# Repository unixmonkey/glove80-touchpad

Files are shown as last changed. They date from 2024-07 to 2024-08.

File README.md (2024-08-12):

# glove80-touchpad
Touchpad sidecar mod for the Glove80 keyboard using the [ERGO Touchpad](https://ergonomictouchpad.com/ergonomic_touchpad.php) ([Amazon](https://www.amazon.com/gp/product/B087Z7RGGK/)).

glove80-touchpad

## Why

I recently started getting RSI-like pain and went on a deep dive into the word of ergonomic split keyboards, but I knew a large part of my issue was my mouse usage habits, and that moving from the keyboard to the mouse (or trackpad) over and over again certainly wasn't helping.

Unfortunately, there currently are very few commercially available ergonomic keyboards that have built-in pointing devices.
However, the [MoErgo Glove80](https://www.moergo.com/collections/glove80-keyboards) keyboard tries to be highly ergonomic, as well as [customizable](https://www.moergo.com/pages/glove80-ergonomic-keyboard-customization) platform, and even provides built-in anchor points and some basic 3d models that can be used to add your own pointing devices right between the thumb cluster and forefinger areas. I figured this could be how I could possibly _make_ the Glove80 the perfect keyboard for me.

So I bought the Glove80, and a 3d printer, and got to work. This is helping me, and so I hope my efforts can help others.

## What you'll need

1. The [MoErgo Glove80 keyboard](https://www.moergo.com/collections/glove80-keyboards)
2. A 3D printer (or a friend/library/makerspace/business with one)
3. [ERGO Touchpad](https://ergonomictouchpad.com/ergonomic_touchpad.php)
4. 2.5mm screws (for the Glove80 mounting holes). I'm using 8mm deep ones I got in [this kit](https://www.amazon.com/dp/B0BLCFD9HR)
5. These [3d model files](/models/)

Optionally, if you want the USB cable to be detachable:

6. Soldering equipment, and a steady hand ([this is a great kit for cheap](https://www.amazon.com/gp/product/B07Q2B4ZY9/ref=ppx_yo_dt_b_search_asin_title?ie=UTF8&th=1))
8. A USB-C breakout board (I used [this treedix board](https://treedix.com/products/treedix-4pcs-usb-type-c-breakout-board-serial-basic-breakout-female-connector-type-pcb-converter-board) also available on [Amazon here](https://www.amazon.com/dp/B096M2HQLK)

## Test the touchpad

While unlikely, it's entirely possible the touchpad may be DOA (Dead on Arrival), so plug it in to a computer and make sure it works before we start questioning our sanity if it somehow no longer works after soldering.

The ERGO works a little different compared to many touchpads, but I found it very easy to adapt to:
- Tap to left-click
- Tap in the top-right corner to right-click
- Slide your finger along the rightmost edge to scroll
- Double-tap to click and hold (useful for dragging windows/files around) - This one takes a little practice
  
ergo-touchpad

It comes with velcro, so if you have a regular sidecar printed, you can use mostly out-of-the-box like that, but I wanted something a bit cleaner.

## 3d printing

This 3d model works pretty well and looks fairly sharp, in my opinion. It's main features are:

- It is expanded to the edge of the thumb cluster, and flares out to completely support the touchpad
- It is perfectly flush to the Ergo touchpad, when the velcro is removed
- It is angled and tilted just a bit to make it easier to use with your index finger
- It has a hole and platform for a USB-C connector and board (optional)
- It has a bottom plate (also optional)

right-hand-touchpad-model
right-hand-touchpad-back

If you want to use on the left-hand of the Glove80, mirror the model along the flat outer surface.

## Assembly

Carefully peel the velcro off of the back of the Ergo touchpad, making sure to not damage the USB cable that is tucked under it.

peel-velcro

Note: Those two green buttons are right and left click, so you could possibly wire them up to actual buttons if desired. I might try a version with a left-click button to make dragging easier.

Now, you should be able to thread the USB cable through the hole in the model, and optionally secure it with some tape on the underside.

If you don't care about a detachable USB cable, you can stop here, and simply screw the sidecar to your Glove80 and stop here.

## Adding a Detachable USB-C Connector

The model includes a small platform and hole for a Treedix USB-C connector & board. This can be used to make it easy to unplug the whole thing at the box, instead of at the computer.

1. Cut the Ergo Touchpad USB cable about 4-5 inches (100-130mm) from the board
2. Score and peel away an inch (~20mm) or so of the protective jacket to expose the USB wires inside
3. On each individual wire, score and peel back each wire to expose about 2-3mm of copper
4. Melt a very small amount of solder onto the exposed copper to get them nice and ready for soldering
5. Melt a very small amount of solder onto the Treedix connector pads where we will be attaching the wires

This is how it should look all wired up:

touchpad soldering

Here it is in the enclosure, with the USB-C board screwed down (this was a version with a circle for a cutout, which didn't have room for the connector, so I had to cut it some. The updated models account for this):

back-view

Then, tuck the wires inside and screw on the back (if you printed that model), with 2.5mm screws (same as the sidecar mounts). This back model could use wider holes to recess those screws.

back-on

## Final product

This is a video of me using both the Touchpad and Trackpoint sidecars, so you can see how the gestures, & wrist positions, & movements look:

Using the Touchpad & Trackpoint (https://youtu.be/VEFaY-3PMP4)

## TODO

- Experiment with the shape of the outer edge
- Possibly wire up buttons to Kailh switches

## See Also

- My [Glove80 Ergo Trackpoint mod](https://github.com/unixmonkey/glove80-trackpoint)
- My [Glove80 Wireless Trackball mod](https://github.com/unixmonkey/glove80-trackball) (in progress)

I love the freedom from RSI pain this keyboard has saved me from, and I love it even more with these mouse-replacements. My pain has gotten much more managable, and I've enjoyed getting into 3d modeling and printing!

Thank you to the many people who have posted on the [MoErgo Discord Community](https://www.moergo.com/discord) that helped inspire me to make this happen, and are always dropping great tips on how to optimize my computing experience.

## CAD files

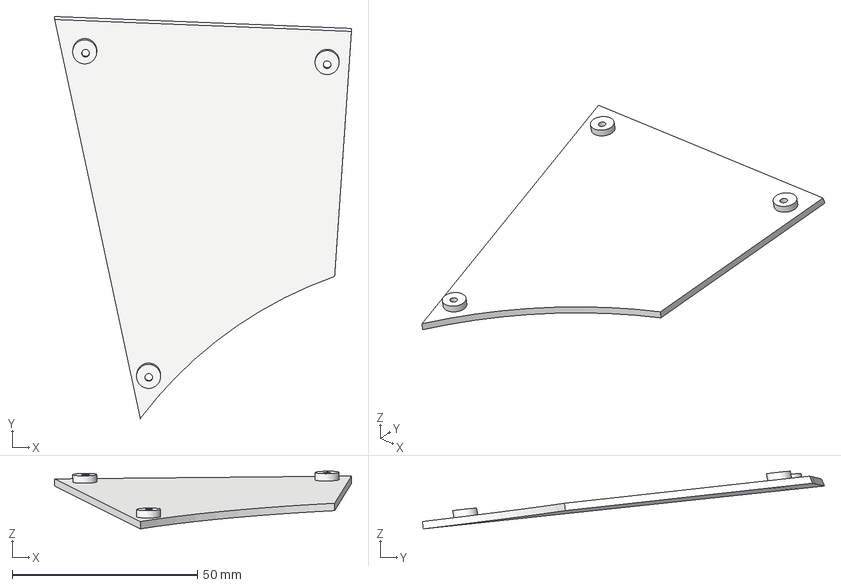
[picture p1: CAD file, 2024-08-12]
models/Right-hand Touchpad Glove80 sidecar bottom.step
80.3 x 108.6 x 15.6 mm

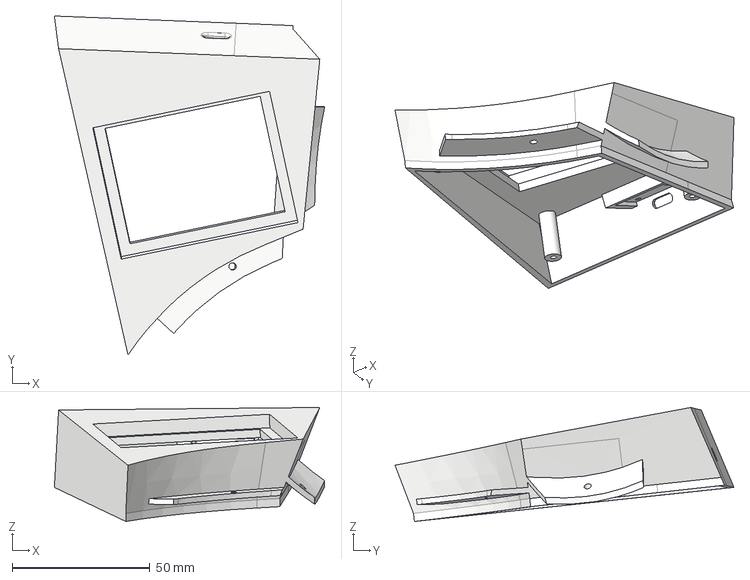
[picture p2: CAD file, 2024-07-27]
models/Right-hand Touchpad Glove80 sidecar top.step
98.1 x 123.0 x 41.4 mm

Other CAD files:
models/Right-hand Touchpad Glove80 sidecar bottom.stl
models/Right-hand Touchpad Glove80 sidecar top.stl

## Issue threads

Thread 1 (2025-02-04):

wireless?

jonogunn, 2025-02-04:
This is a great mod! I'd love to try it but I'm looking for a wireless option. Do you have plans on trying out wireless touchpads?

unixmonkey, 2025-02-04:
This kit can be made wireless with a USB battery bank, and the [Handheld Scientific](https://handheldsci.com/kb/) adapter. I know for sure because I have one, and just plugged it in to verify while typing this out.

Aside from that, I'm unaware of any wireless touchpads small enough to work in this form factor, and not all that interested in designing custom controllers or circuits, but if you find a good ready-made kit, or something that plugs into the GPIO pins of the Glove80, please let me know. I'm sure many people would be very interested.

jonogunn, 2025-02-05:
Is your usb bank and adapter method documented at all?

unixmonkey, 2025-02-05:
It’s just how that adapter works.
You plug a keyboard or mouse into one end, and USB power into the other, and it shows up as a Bluetooth keyboard and “just works”.

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

jonogunn, 2025-02-05:
ah i see now. thanks!

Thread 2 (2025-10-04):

How to print for beginners?

wondering639, 2025-10-04:
First of all, thanks for making and providing this. I have never used a 3D printer before, but want to print this sidecar in hackerspace. I have some beginner questions before, specific to this sidecar mod:
1. PLA or PETG, what would you recommend for best results?
2. In Bambu Studio I get these warnings:

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

How to handle these and are they intended?

Thanks!

unixmonkey, 2025-10-04:
This is a pretty standard warning that your 3d printer can't print stuff that is floating in mid-air, it has to also print support material under it.

In Bambu Studio, first you should orient your part on it's largest, flattest face (usually). This can be done by clicking the object, then clicking the "Lay on Face" tool (on the top), and possibly choosing the face you want to be on the bottom. I would suggest the top face be printed face-down. This will give the top of the sidecar a smoother, nicer looking face.

Then, because this part has "floating regions" that aren't touching the plate, this needs support material printed also. In the left-hand menu, there's a "Support" tab, with an "Enable Support" checkbox. Checking this will add supports that will print along with the part, but can be snapped off easily (usually) when it's done.

All that above said, I've just pushed a change to this project to include a set of print-ready plates for Bambu Studio. You should be able to open the `.3mf` file, and just choose your filament and plate type, and hit "Slice plate" then "Print plate".

It's this file here: https://github.com/unixmonkey/glove80-touchpad/blob/main/ready-to-print/Glove80%20TouchPad%20Bambu%20Plates.3mf

Here's what it should look like with those supports after slicing:

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

Then after printing, you can carefully rock the supports off, and peel away the brim. The ones under the USB plate you can just leave attached if you like (I did for mine), but otherwise you might need to get in there with needlenose pliers or a pocketknife.

I hope this helps! Please let me know how it goes, or if you have questions!

wondering639, 2025-10-05:
@unixmonkey awesome, thanks for your explanations and the ready to print version! Just a follow up question: I want the easy way with keeping the cable (no USB-C modification). In that case, how does one get the cable from the inside to the outside? The only hole is the one for USB-C, which is too small to put the USB-A through it? What am I missing here? Or is the idea to not use the bottom plate to get the USB-A cable out? Thanks!

unixmonkey, 2025-10-06:
You could cut or drill a little notch on either part where they meet, big enough for just the cable.

Here’s a short tutorial on punching holes in Bambu Studio if you’d rather have it built in: https://m.youtube.com/watch?v=OsA23WCxRtg

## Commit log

2024-07-27 Commit current version of models
    [Right-hand Touchpad Glove80 sidecar bottom.step, Right-hand Touchpad Glove80 sidecar bottom.stl, Right-hand Touchpad Glove80 sidecar top.step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]
2024-08-12 Make screw recesses wider
    [Right-hand Touchpad Glove80 sidecar bottom.step, Right-hand Touchpad Glove80 sidecar bottom.stl]
